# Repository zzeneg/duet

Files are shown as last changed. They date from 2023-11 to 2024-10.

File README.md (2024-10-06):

# duet

Wireless unibody/unsplit portable keyboard.

(https://www.youtube.com/watch?v=R7SToNp1SO8)

> [!NOTE]
> One duet is [available for purchase](https://www.reddit.com/r/mechmarket/comments/1fwzixb/eupl_h_duet_stront40_custom_ergo_keyboards_w/) right now

## Features

- wireless (nice!nano MCU)
- unibody that can be disassembled into two parts for traveling
- 40 Choc V1 switches
- 1 rotary encoder and 1 five-way switch
- reversible PCB
- 3D printed case
- nice!view support

## Photos

https://github.com/zzeneg/duet/assets/910255/740595a8-76a9-42da-903d-3cff3896a925

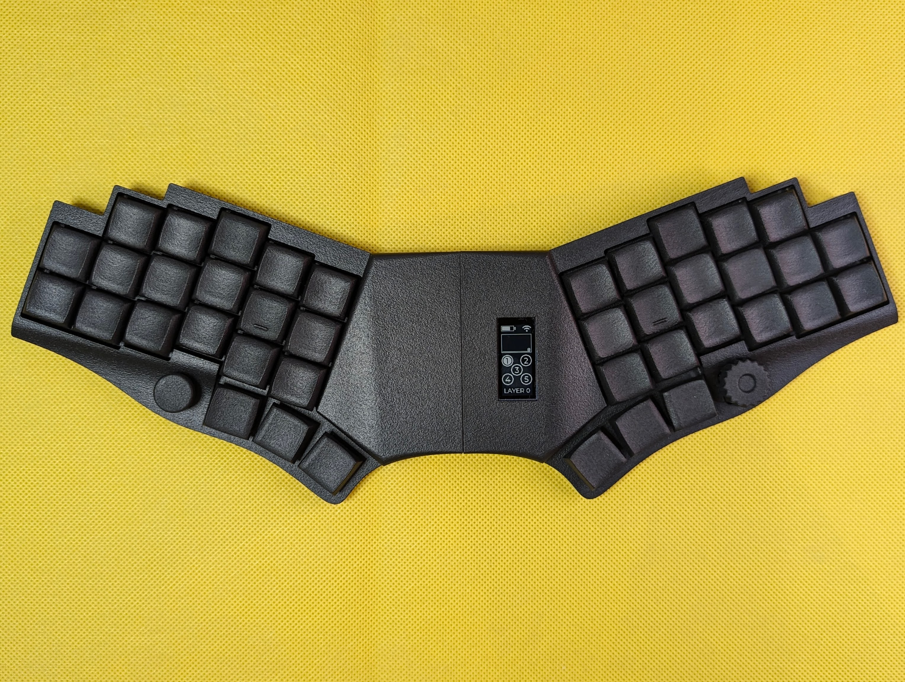
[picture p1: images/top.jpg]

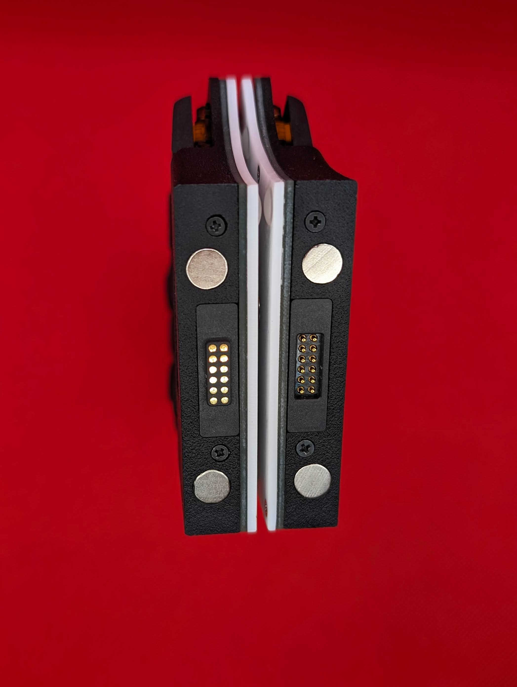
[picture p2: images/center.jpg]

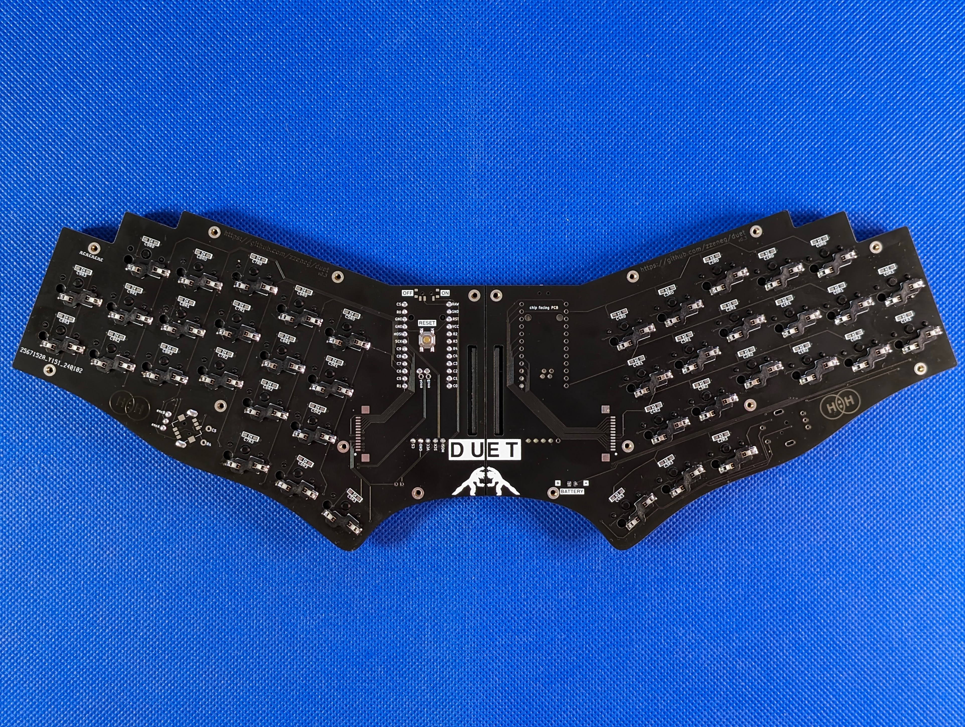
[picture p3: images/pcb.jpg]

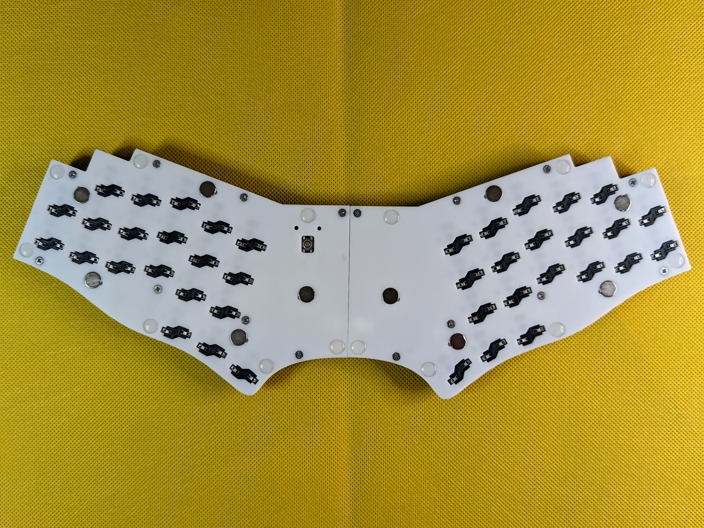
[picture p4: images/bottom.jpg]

[...more](./images)

## Firmware

[zmk-config](https://github.com/zzeneg/zmk-config/tree/duet) - my custom keymap, use it for testing only. Fork and create your own keymap instead.

## Instructions

[Build guide](./guide/readme.md)

All files are available in repo or [GitHub release](https://github.com/zzeneg/duet/releases/latest).

## Support

If you like my work and want to support my future designs, please consider [sponsorship](https://github.com/sponsors/zzeneg).

#### Sponsors



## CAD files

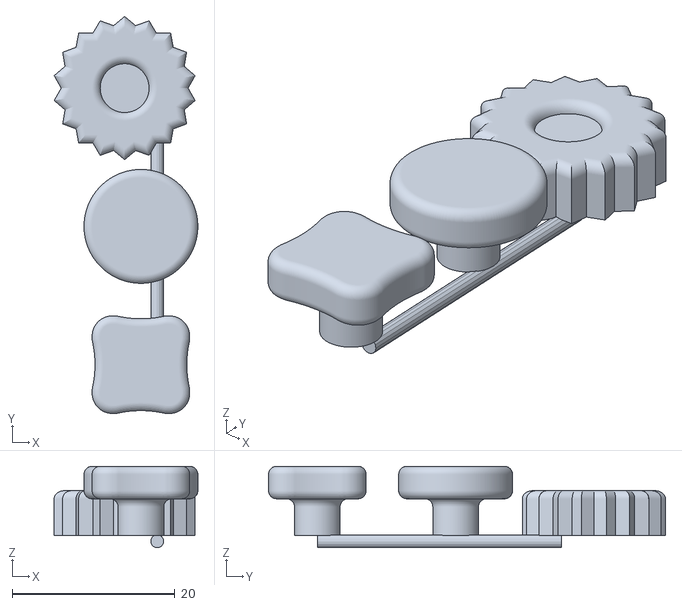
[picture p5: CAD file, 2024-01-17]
case/knobs-all.stl
17.7 x 48.8 x 10.0

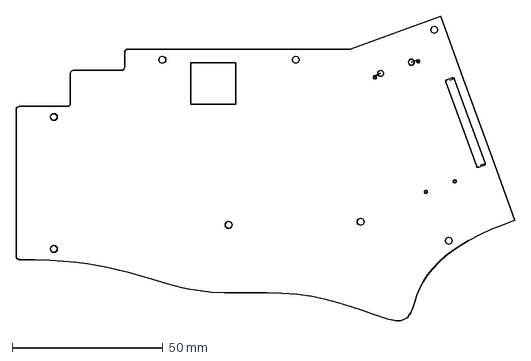
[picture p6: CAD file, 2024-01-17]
pcb/outline.dxf
165.5 x 101.1 mm

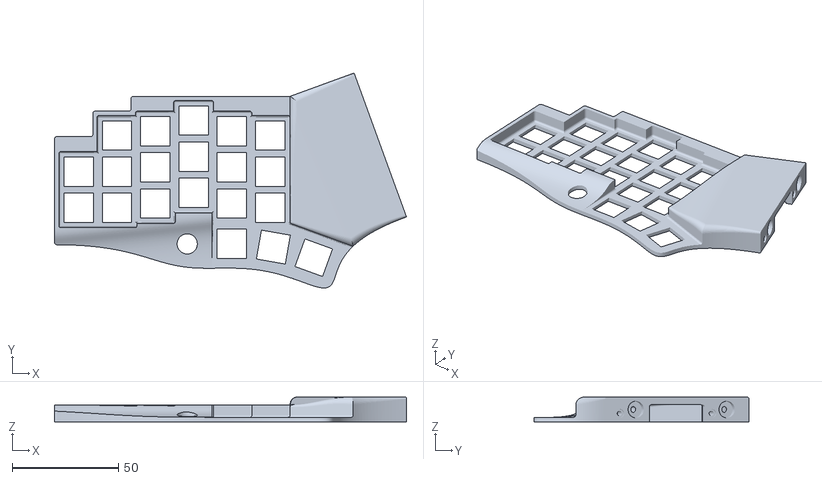
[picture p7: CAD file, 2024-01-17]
case/case_duet v39_top-left-cover.stl
165.5 x 101.1 x 11.7

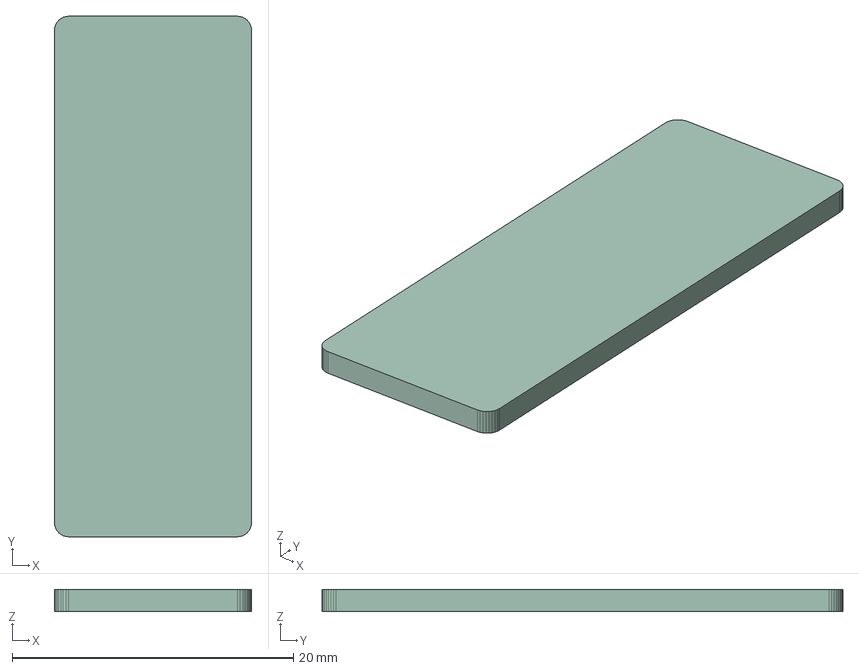
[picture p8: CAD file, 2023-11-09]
pcb/logo.step
14.0 x 37.0 x 1.58 mm

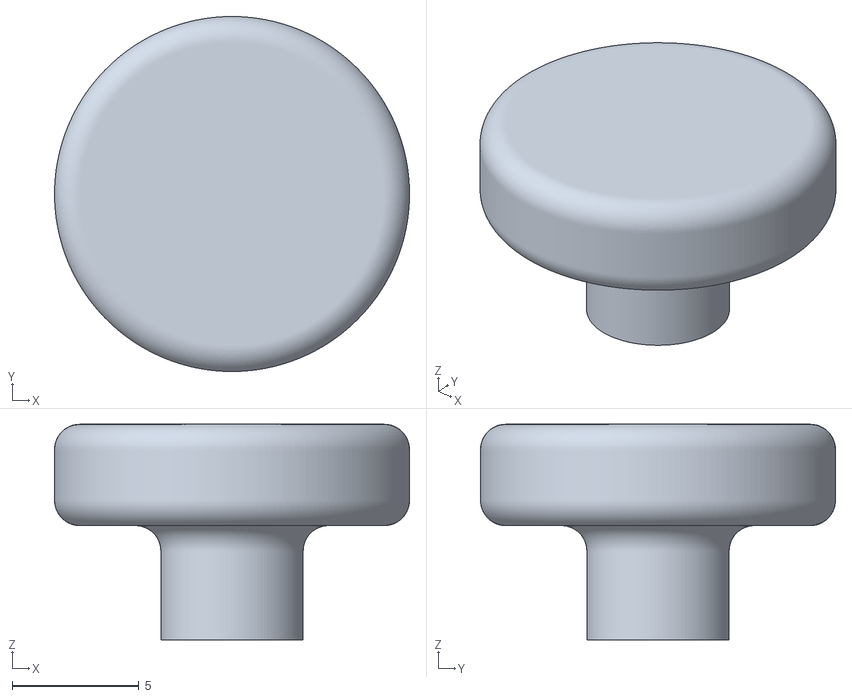
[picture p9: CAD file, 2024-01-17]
case/knob-5way-round.stl
14.0 x 14.0 x 8.50

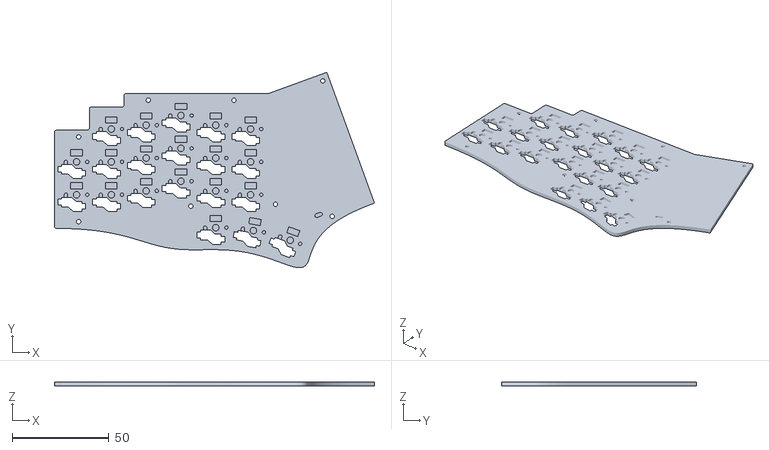
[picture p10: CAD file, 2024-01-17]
case/case_duet v39_bottom-left.stl
165.5 x 101.1 x 2.00

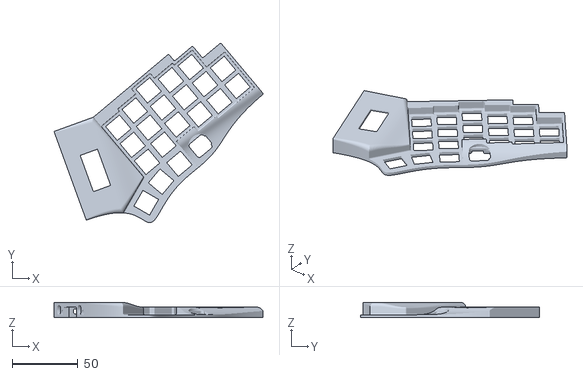
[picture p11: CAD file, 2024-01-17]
case/case_duet v39_top-right-display.stl
159.4 x 136.7 x 11.7

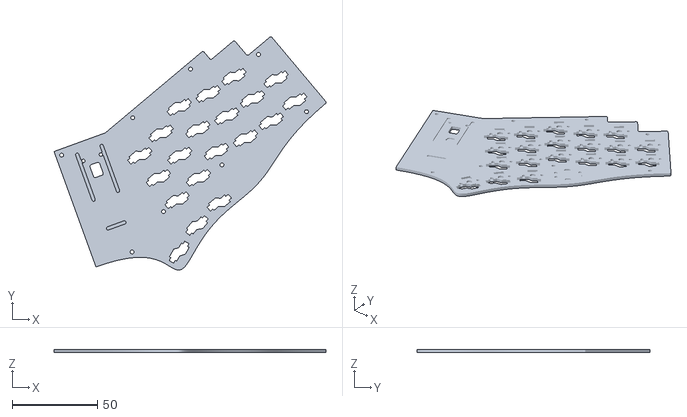
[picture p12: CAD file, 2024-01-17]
case/case_duet v39_bottom-right.stl
159.4 x 136.7 x 2.00

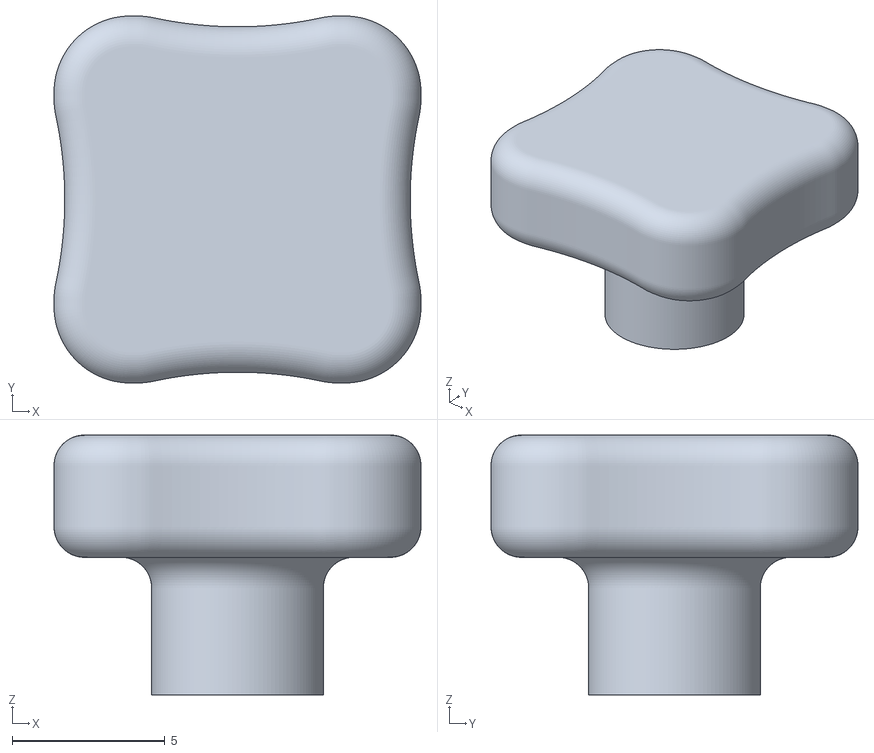
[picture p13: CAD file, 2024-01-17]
case/knob-5way-ergo.stl
12.0 x 12.0 x 8.50

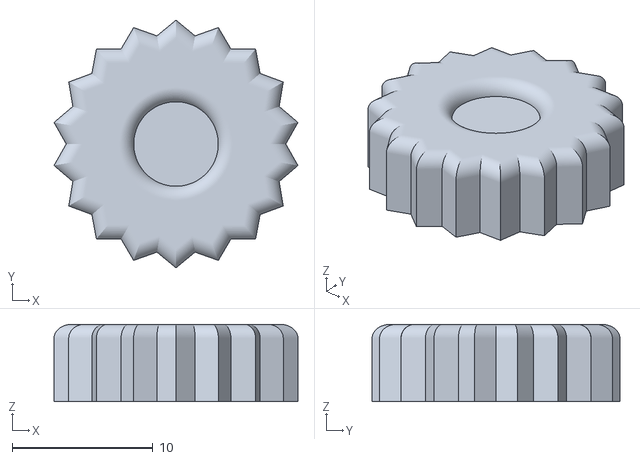
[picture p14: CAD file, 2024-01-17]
case/knob-ec12.stl
17.3 x 17.6 x 5.50

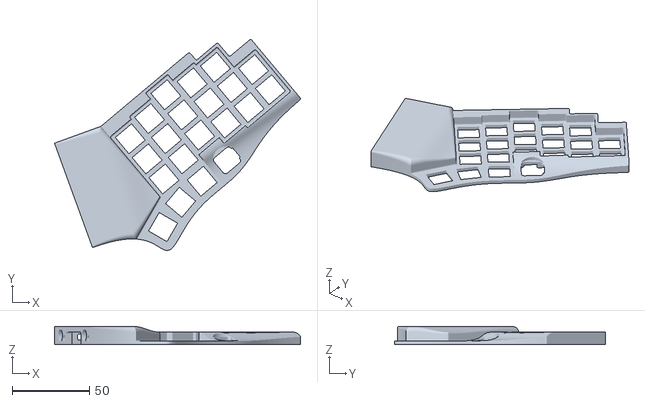
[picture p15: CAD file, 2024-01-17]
case/case_duet v39_top-right.stl
159.4 x 136.7 x 11.7

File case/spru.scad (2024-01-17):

count = 3;
spacing = 17;
r = 0.8;

stl1 ="./knob-5way-ergo.stl";
stl2 ="./knob-5way-round.stl";
stl3 ="./knob-ec12.stl";

union() {
    import(stl1);
    translate([0, spacing, 0]) import(stl2);
    translate([-2, spacing * 2, 0]) import(stl3);

    translate([2, 0, - 0.9 * r])
    rotate ([270, 0, 0])
    cylinder(h = (count) * spacing - 21, r = r, $fn=15)
    ;
};

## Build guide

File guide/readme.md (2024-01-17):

## What to order

All files are availaible in repo or in [Release](https://github.com/zzeneg/duet/releases/latest)

- 2 PCBs - `GERBER-pcb.zip` and `GERBER-connector.zip`. For connector I recommend to select 1.2mm thickness. If using JLCPCB, choose "Specify a location" in "Remove order number". Other settings can be default
- 4 case parts - bottom left, bottom right, top left and top right (with or without display)
- 2 knobs - I recommend `knobs-all.stl` which contains EC12 knob and two knobs for 5 way switch

## Bill of materials

- MCU - nice!nano _(recommended, please support original creator)_ or its chinese clone
- 40 Choc V1 hotswap sockets
- 40 Choc V1 switches
- 40 [SMD SOD-123 1N4148](https://www.aliexpress.com/item/1005002882901030.html) diodes
- Battery up to 602040 size - this is what I'm using, should be enough but you may try to go bigger (check that there's enough space inside using 3D project)
- _[Optional]_ Vertical 2pin 2.54mm JST [connector](https://www.aliexpress.com/item/1005004938361514.html) for battery
- [Magnetic connector 12pin](https://www.aliexpress.com/item/1005004609718442.html)
- 1 EC11/EC12 rotary encoder, [low profile EC12](https://www.aliexpress.com/item/1005003636548797.html) is recommended (no click though)
- 1 Alps SKRH 5-way switch, [SKRHADE010](https://www.aliexpress.com/item/1005005687595092.html) (more tactile) or [SKRHABE010](https://www.aliexpress.com/item/1005004045054939.html)
- 6mm, 8mm and 10mm [M2 screws with flat head](https://www.aliexpress.com/item/4001248931159.html) (choose black or silver based on case color/preference)
- [M2 nuts](https://www.aliexpress.com/item/1005001412230125.html)
- Vertical 12pin 1mm [FFC/FPC connector](https://www.aliexpress.com/item/1005003970200102.html)
- Horizontal 12pin 1mm [FFC/FPC connector](https://www.aliexpress.com/item/10000348360254.html)
- 12pin 1mm pitch 6cm [FFC cable](https://www.aliexpress.com/item/10000013182312.html) - grab both reverse and same side variants, in case you solder the connector upside down
- SMD 4x4x1.5mm [push button](https://www.aliexpress.com/item/32802382507.html)
- MSK-12C02 on/off switch
- [7x1.5mm legs](https://www.aliexpress.com/item/1005002995402961.html)
- [8x1.5mm magnets](https://www.aliexpress.com/item/1005005884332595.html)
- 2.54mm female pin [headers](https://www.aliexpress.com/item/4001122376295.html)
- 5pin [headers](https://www.aliexpress.com/item/1005005742644313.html) - source of pins for socketing, and also a connector for nice!view
- M2 4mm [heatset inserts](https://www.aliexpress.com/item/1005004624377733.html) - diameter 3.2mm for resin case or 3.5mm for thermoplastic

If using nice!view:

- [5pin female RGBW cable](https://www.aliexpress.com/item/1005002644712420.html)

## Tools

- Soldering iron. Any iron will work, but I highly recommend something small like TS100 or Pinecil with TS-K tip, it's good for SMD soldering
- Solder wire, preferably with lead if you can get one. For EU I recommend this [shop](https://botland.store) and Cynel brand, 0.56mm and 0.9mm
- [Flux](https://www.aliexpress.com/item/1005004675178847.html)
- Flush cutters - be extra careful when cutting pins, always use eye protection
- Hot glue (for nice!view only), instant glue (for resin case only)
- Tweezers (I prefer [reverse](https://www.aliexpress.com/item/1005004188266714.html) instead of regular), pliers, soldering mat, isopropyl alcohol (IPA) and [cotton pads](https://www.aliexpress.com/item/1005003798227116.html) for cleaning

## Preparations

- download sample firmware, flash it to MCU and pair with your PC. It's easier to do it now and also check that MCU actually works
- read through the whole build guide. Split your components into three groups - left side, right side and connector

## Left side

1. Left side components:

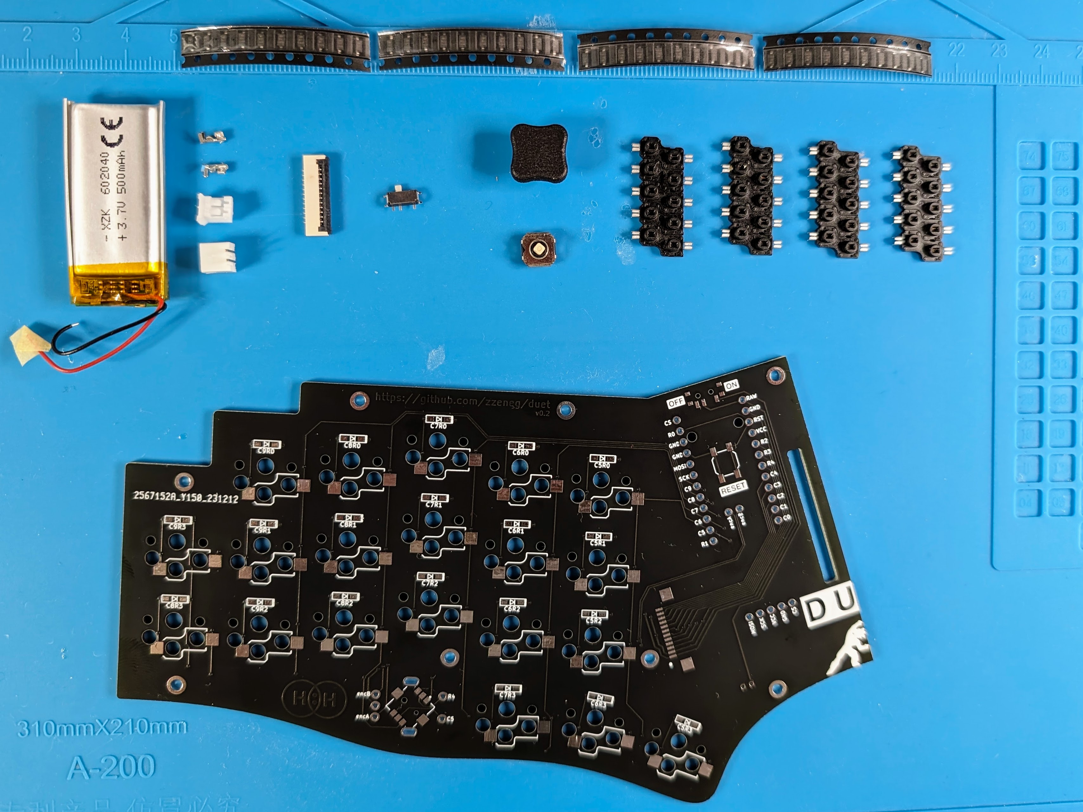
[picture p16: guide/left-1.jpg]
   

2. Start from FFC connector, so you'll not be able to mix left and right sides anymore. As with any SMD part, start with putting some solder on only **one** big pad.

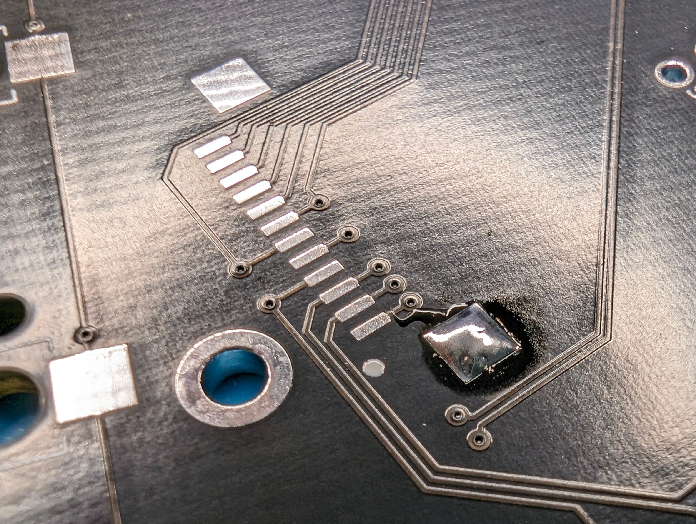
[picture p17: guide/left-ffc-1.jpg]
   

   Put the part into place, heat the solder blob and align the part to match other pads.

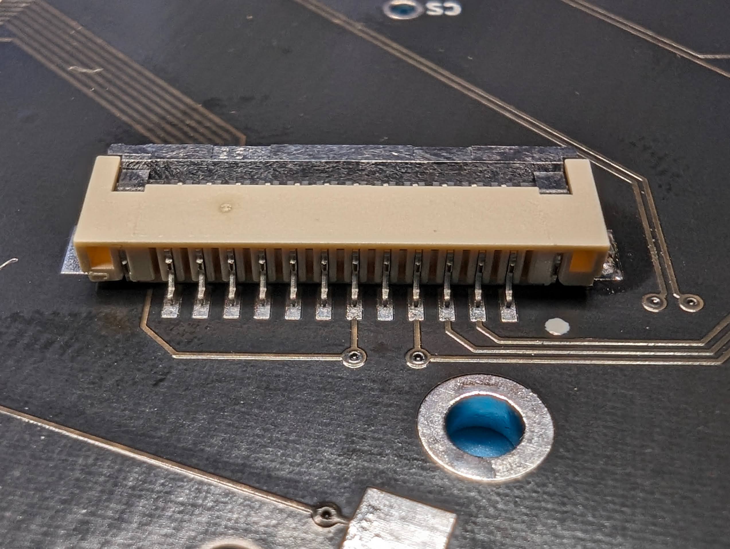
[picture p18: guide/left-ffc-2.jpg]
   

   Solder the second big pad, then proceed to pins. Don't drag the iron across pins, just solder them with the tip one by one, slowly and carefully. Use flux if you have it, clean with IPA afterwards.

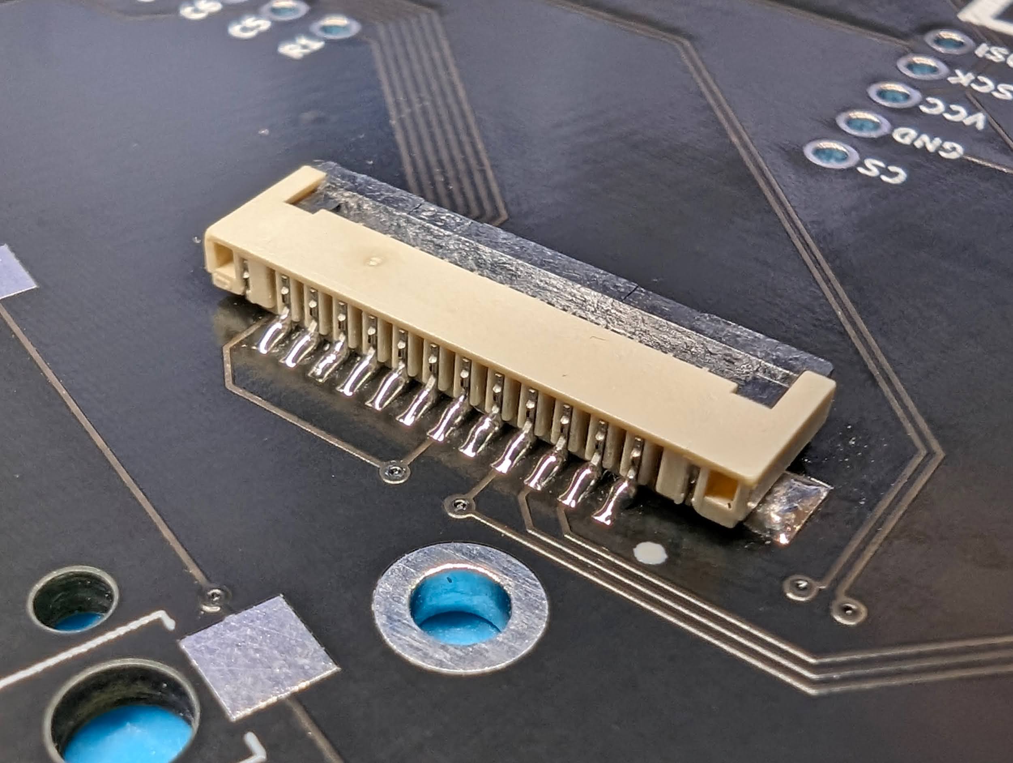
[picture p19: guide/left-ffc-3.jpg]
   
   
   If any pins are bridged, add flux and remove extra solder by moving the iron along the pin from component to you. Again, slowly and patiently, it can take multiple tries but you can do it.

3. Solder on/off switch. Same approach - start with one pad, put switch into place and finish other pins.

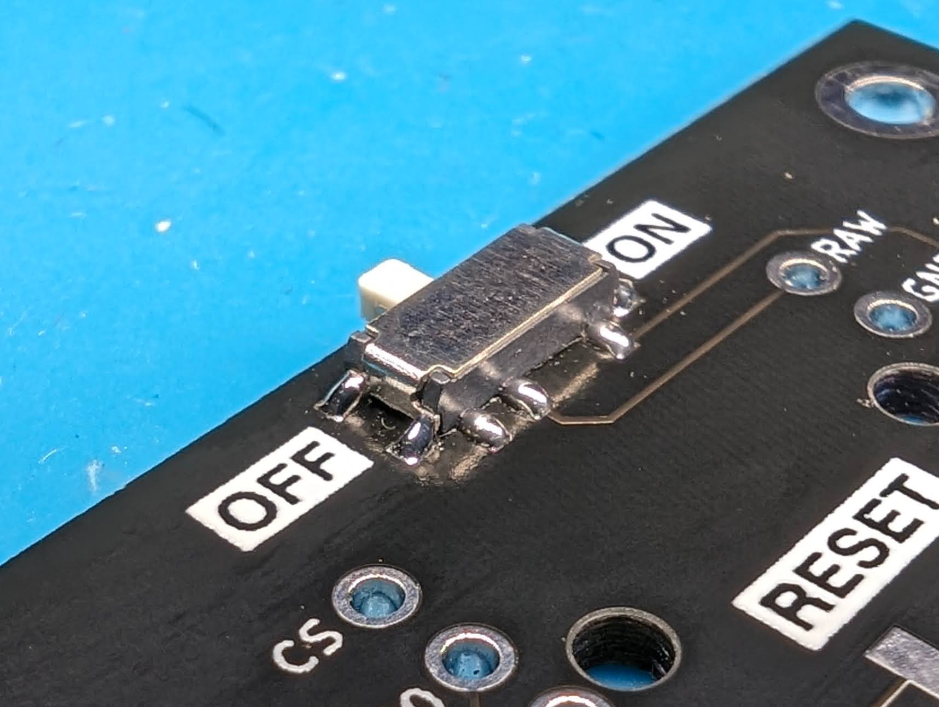
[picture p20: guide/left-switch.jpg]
   

4. Time for diodes. The PCB and case supports diodes both on any side. I prefer putting them on top inside switch's LED hole - it's pretty big and allows more relaxed placement. As to my knowledge, all Choc switches support LEDs, but double check your switches to be sure.

   Diodes are **not** symmetrical, make sure you're placing them correctly. Every diode has a vertical line on it marking the side with cathode, experiment with lighting and angle if you don't see it. That line should match with a vertical line inside the PCB's footprint and a thick border line (so you can verify it after soldering).

   Start with one pad, use tweezers to put the diode into place. Make sure to press on it with fingernail to avoid it floating in the air. Double check diode's orientation and solder second pad. If you're comfortable with SMD soldering already I recommend to do one pad for all diodes first, then place them and solder second pad for all of them at once.

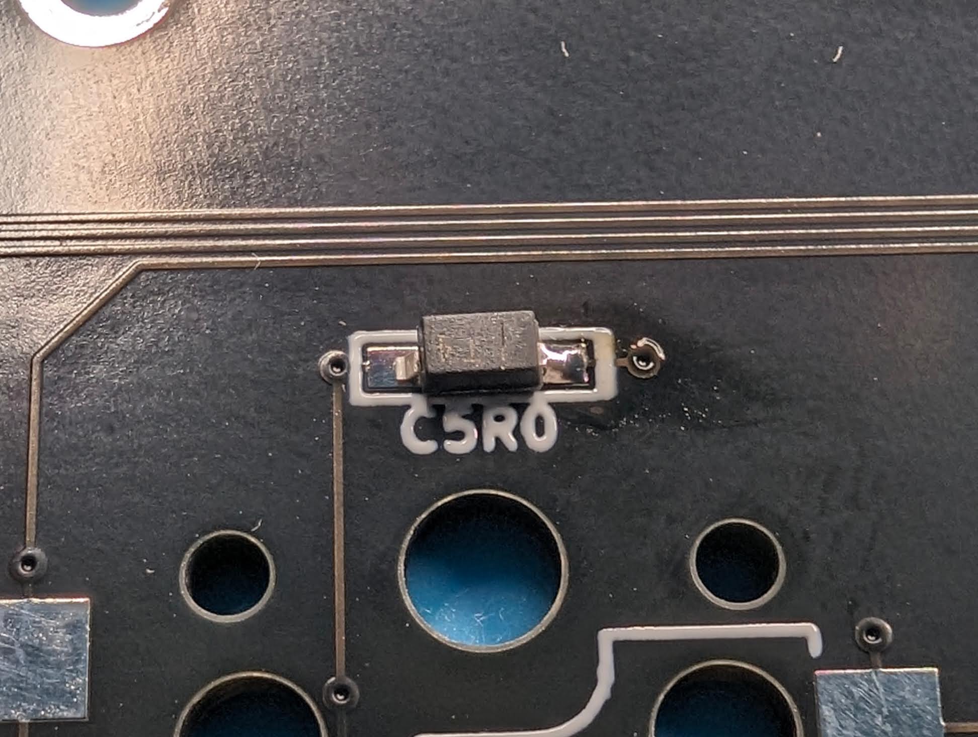
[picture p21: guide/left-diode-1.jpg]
   

5. **Flip** the PCB, let's do hotswap sockets now. Much easier to work with, thicker solder wire is recommended, you'll need a lot. Sockets are not symmetrical, look at silkscreen on how to place it. Approach is still the same - first pad, then socket, then second pad. Make sure that socket is fully inserted into the PCB.

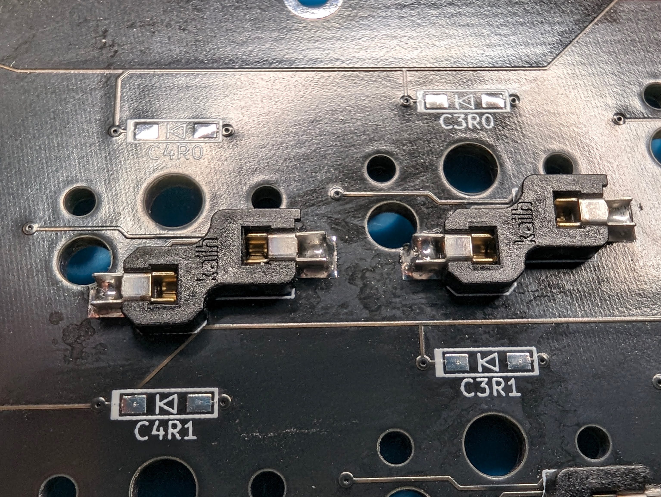
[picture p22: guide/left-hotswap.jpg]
   

6. _[Optional]_ Solder JST battery connector. When attaching a battery, double check polarity, positive side (red wire) must match with + symbol on silkscreen - depending on your battery you may have to swap wires inside the connector. You can fix the battery in place with tape (use removable tape and/or try it inside the case first).

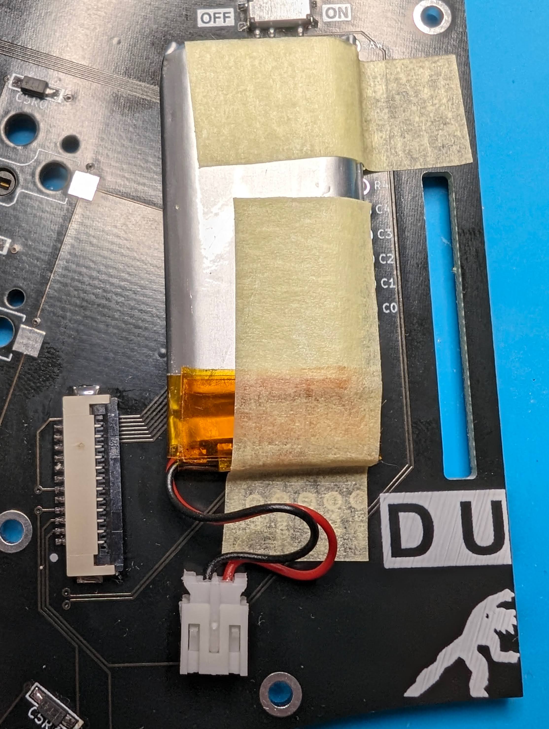
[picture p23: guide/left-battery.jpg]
   

7. Flip PCB again, last part - 5 way switch. It's not symmetrical, there is only one way you can insert it so do not force it. Start with big pads, finish with small ones.

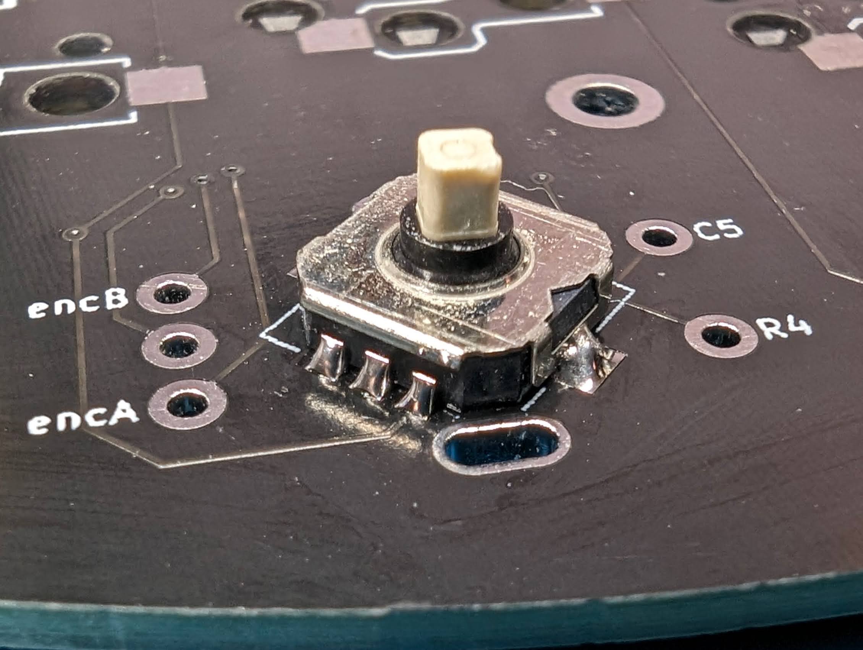
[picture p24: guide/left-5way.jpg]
   

   Left side is finished, congratulations!

## Right side

1. Right side components:

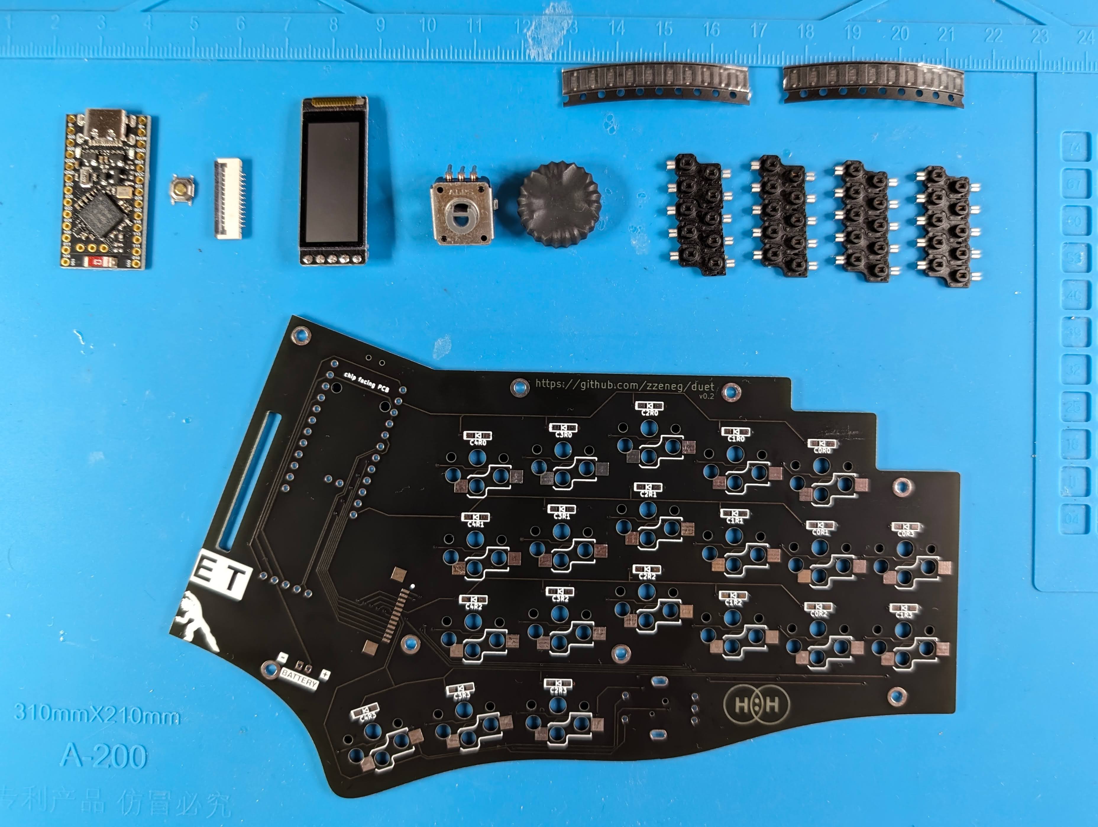
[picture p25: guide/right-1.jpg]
   

2. Same as the left side - start with FFC, then diodes and sockets (on the bottom side).

3. Prepare MCU headers - you'll need two strips of 12 pins and one of 2. Don't try to break the header between the pins, instead count the required number of pins, and break in middle of a next pin. Discard that pin and cut the plastic with flush cutters - it'll look much better. Assemble headers like this (using extra headers for stabilization):

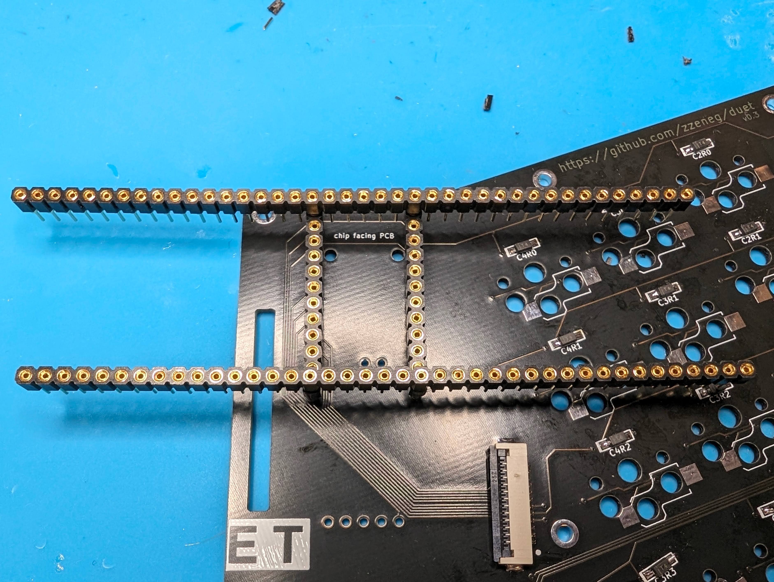
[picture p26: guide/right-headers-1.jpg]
   

   Flip carefully and solder all pins starting from corners. I prefer to cut first and then solder but you can cut afterwards as well, just remember to do it as bottom case has only 1.2mm space there.

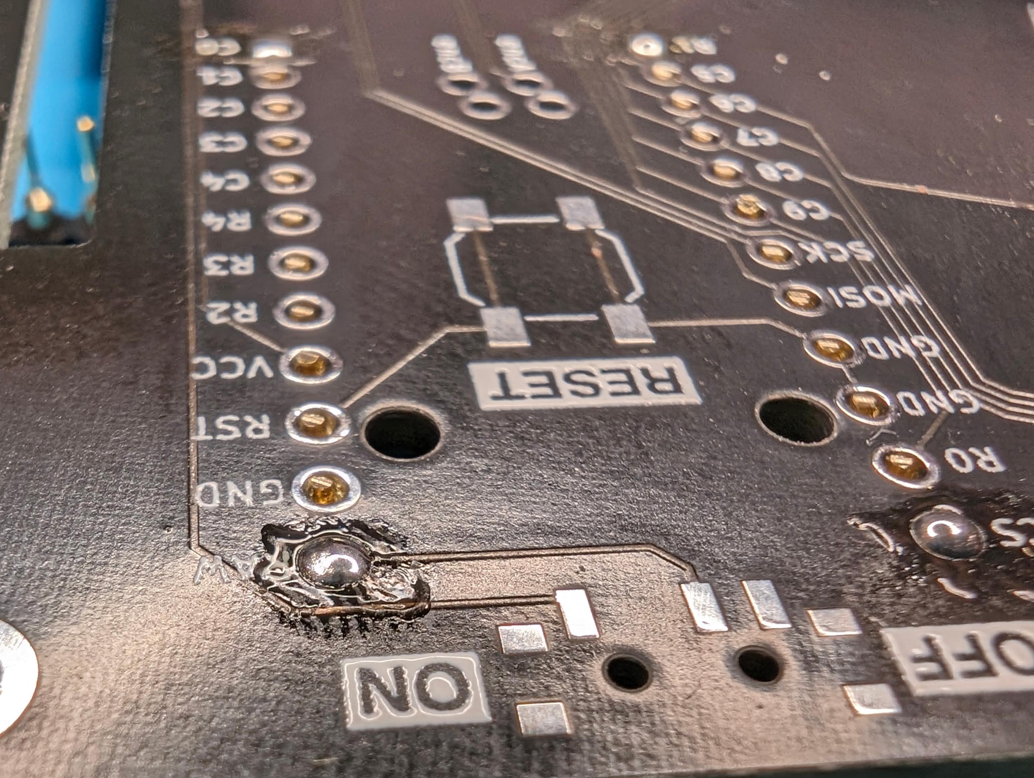
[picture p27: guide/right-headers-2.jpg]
   

   If you're using original nice!nano: insert 2-pin header into **top** holes (like on photos) and fix it in place with an extra pin header. If you're using clone: insert 2-pin header into **bottom** holes and fix it in place with tape (holes are not aligned so you can't use headers). Flip and solder.

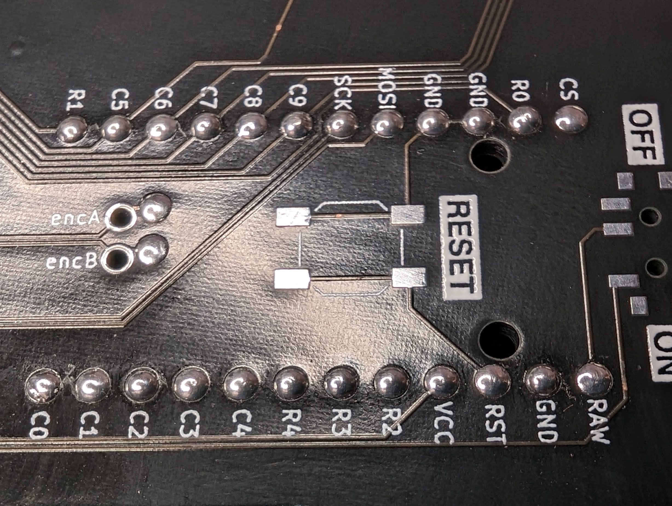
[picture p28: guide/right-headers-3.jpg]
    

5. Solder reset button. SMD parts should be a piece of cake for you already, so no photos :)

6. Time to actually socket the MCU.

   For **nice!nano** users - you have to cut plastic around the pin in the middle, n!n has some component in that place:

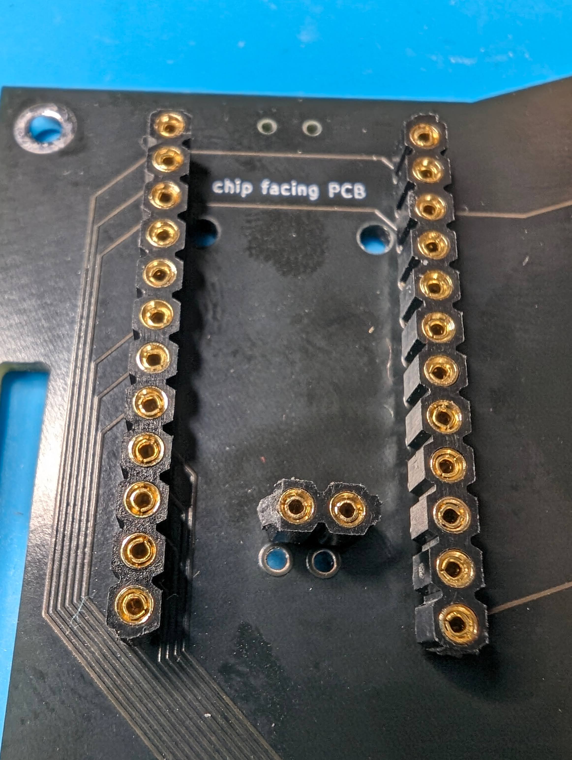
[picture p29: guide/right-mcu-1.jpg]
   

   Pull out 24 pins from RGB headers and put a piece of masking tape over all headers leaving some space in between for MCU components.

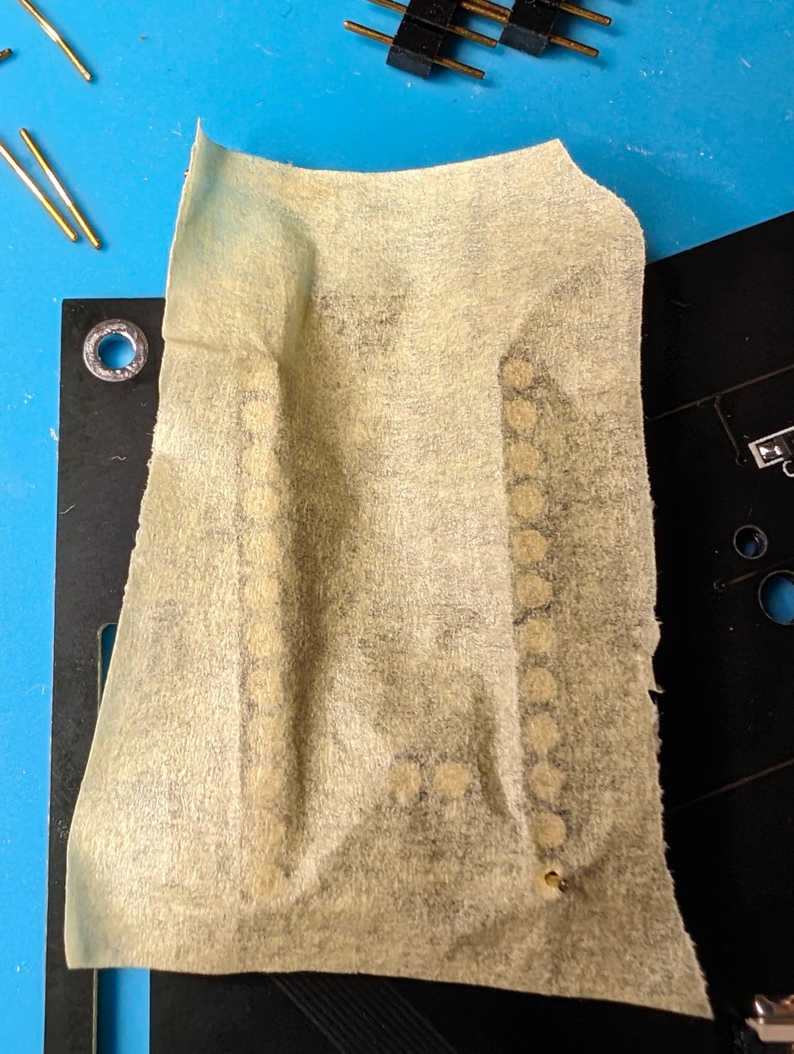
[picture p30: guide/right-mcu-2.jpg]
   

   Align MCU holes with headers (remember to ignore top holes on MCU, they are not used/soldered) and insert pins one by one. Cut them if you prefer but it's not required. Solder everything starting from corners. For **nice!nano** be extra careful not to bridge middle pins with SWC pad.

   Carefully extract MCU, remove tape and insert it back. Done!

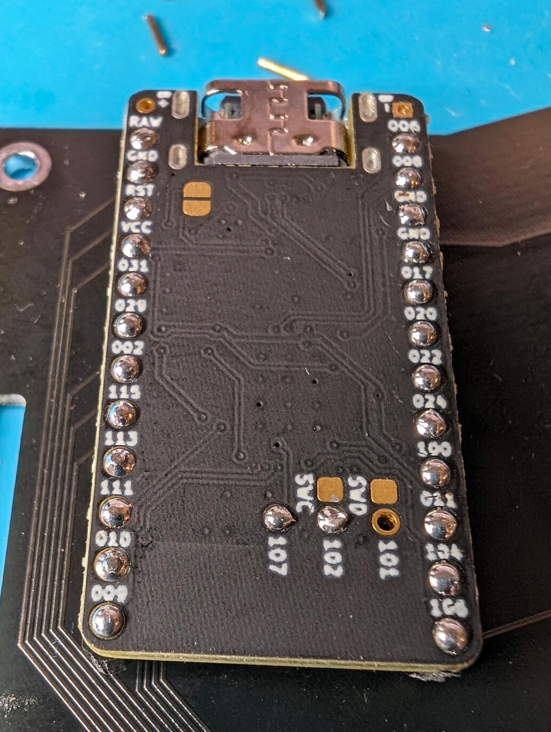
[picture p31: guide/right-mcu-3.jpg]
   

7. Solder rotary encoder, remember to cut pins under 1.2mm.

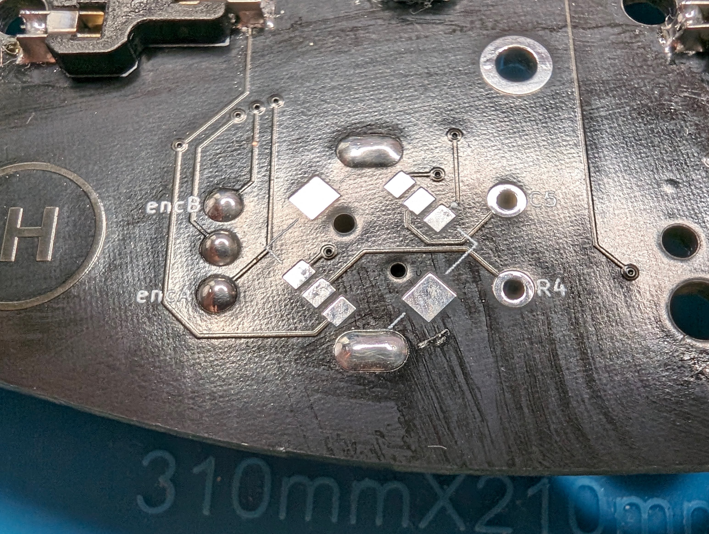
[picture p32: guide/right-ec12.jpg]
   

8. _[Optional]_ **nice!view**. You could solder it with wires directly but I like to socket it similar to MCU to make disassembly much easier. Cut the RGB strip to 6.5-7cm, clean the ends and solder them to **keyboard** PCB.

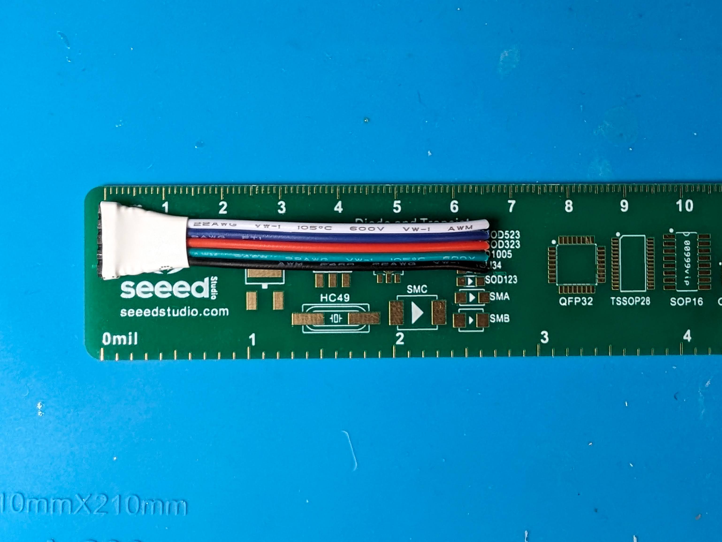
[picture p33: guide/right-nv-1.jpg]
   

   Take an RGB header, bend pins on one side, insert it into nice!view and solder. Do not bend the header inside nice!view to avoid damaging the display.

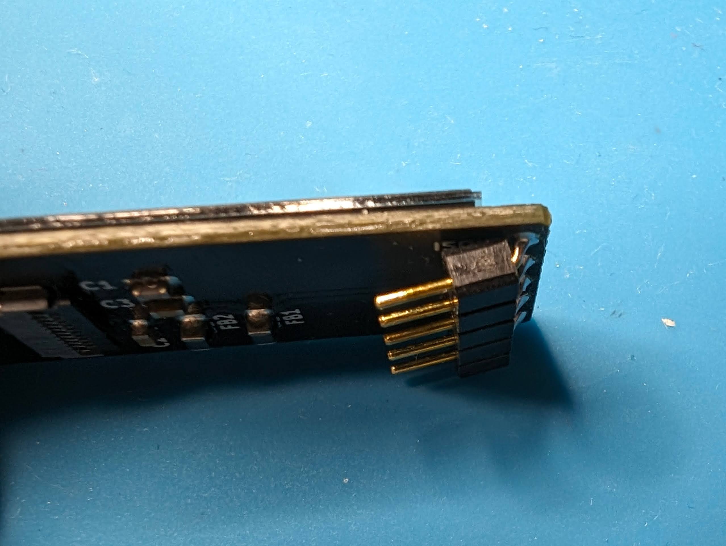
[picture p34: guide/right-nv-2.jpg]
   

   Glue nice!view to the case with hot glue or tape.

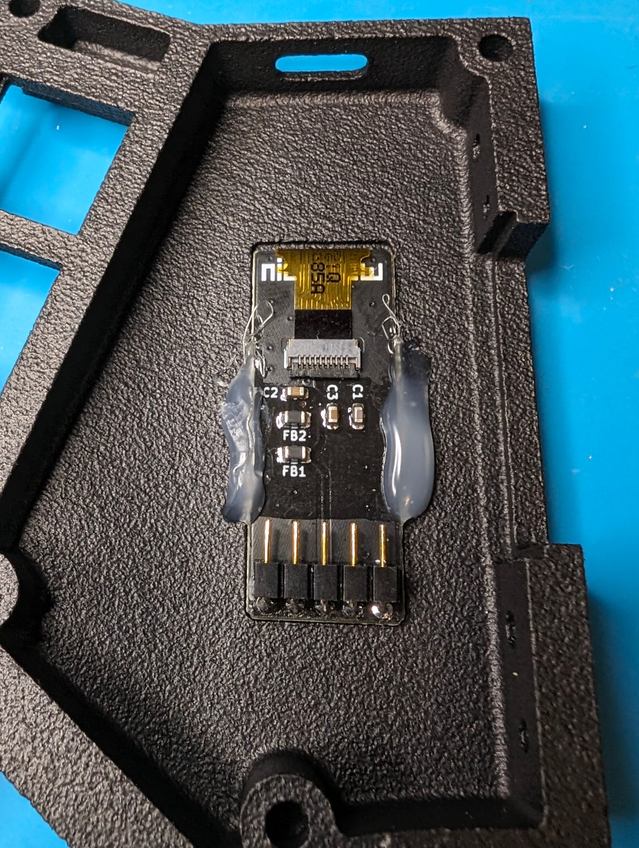
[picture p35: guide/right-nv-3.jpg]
   

   Bend the wire into an S letter (see photo), attach it to nice!view and try to close the case, the wire must bend before reaching MCU:

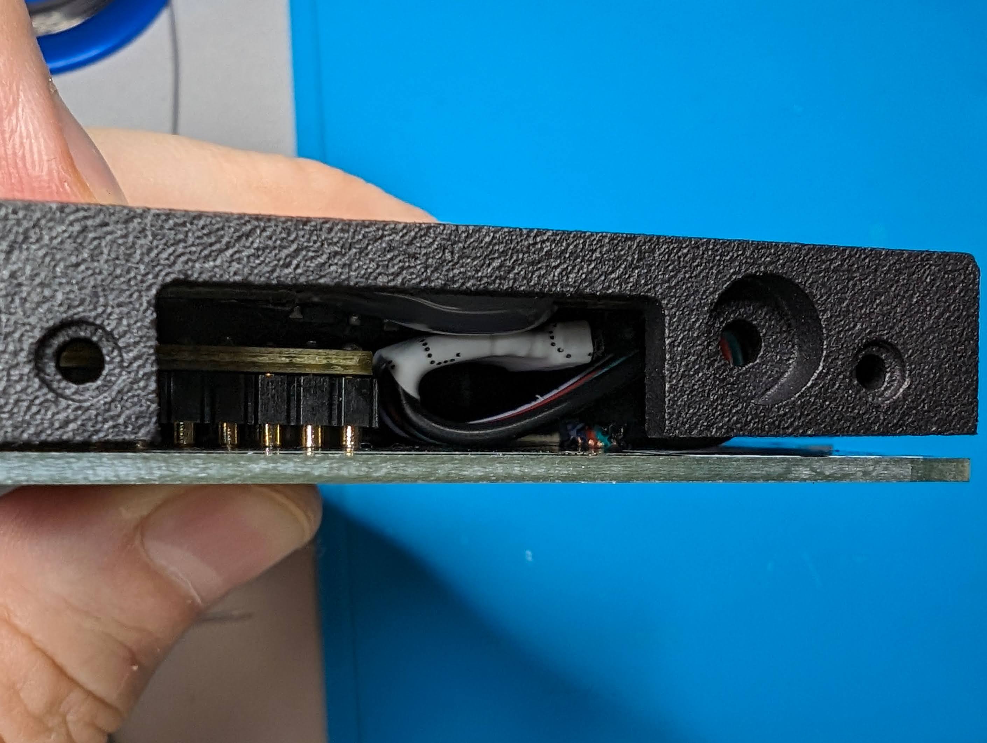
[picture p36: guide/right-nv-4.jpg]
   

   Right side is completed.

## Connectors

Now this part is a bit confusing, look carefully on the photos and triple check your magnets for correct orientation.

1. Prepare two connector PCBs, and put them down on **different** sides (for example jlcpcb's order number should be visible only on one of them). Rotate so that version number (`0.3`, `1.0`, etc) is on top. Solder vertical FFC connectors, black part must be on **top** (next to version number). If you still soldered it upside down, don't worry and use another FFC cable (with contacts on different sides).

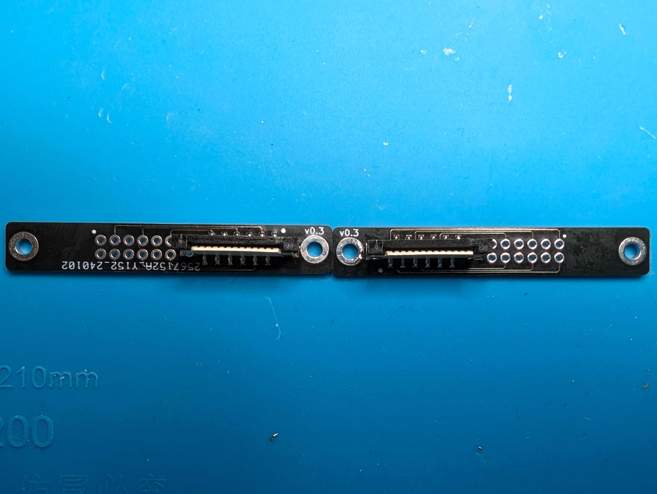
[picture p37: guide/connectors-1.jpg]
   

2. Take magnetic connectors and put some tape on magnets to isolate them, otherwise they'll short PCB pads.

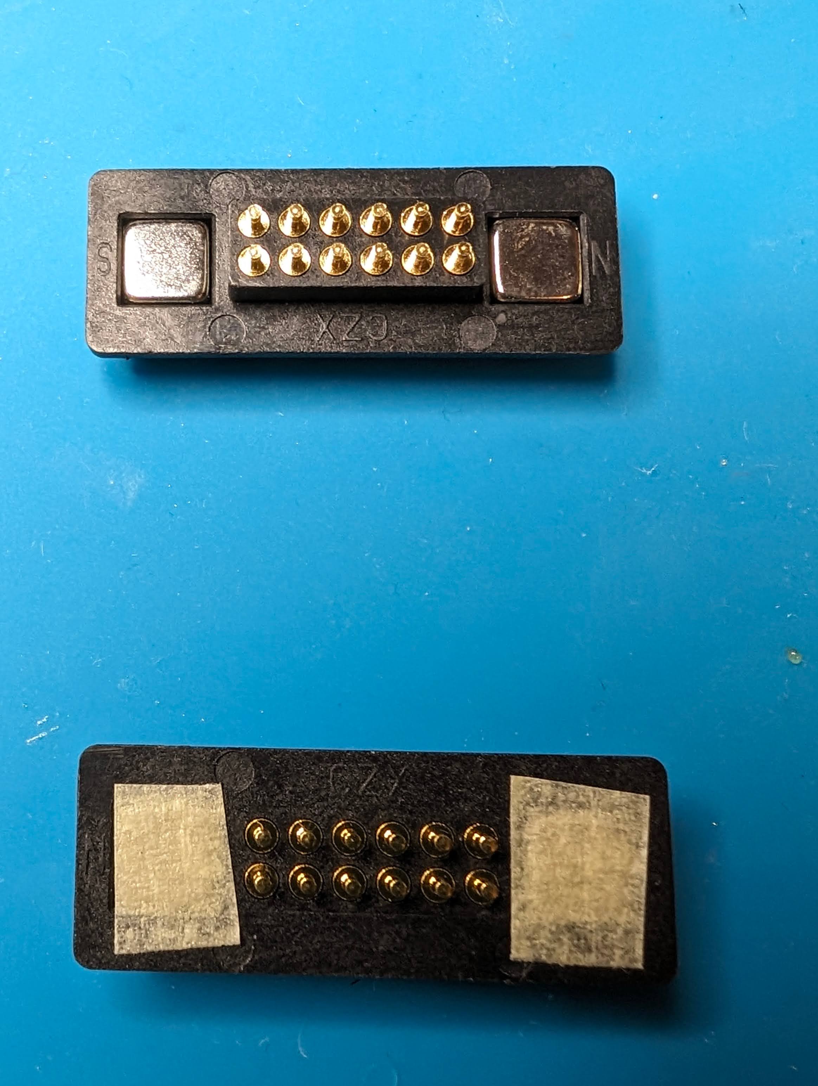
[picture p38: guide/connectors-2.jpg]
   

3. Put PCBs onto connectors and double check that magnets are oriented correctly

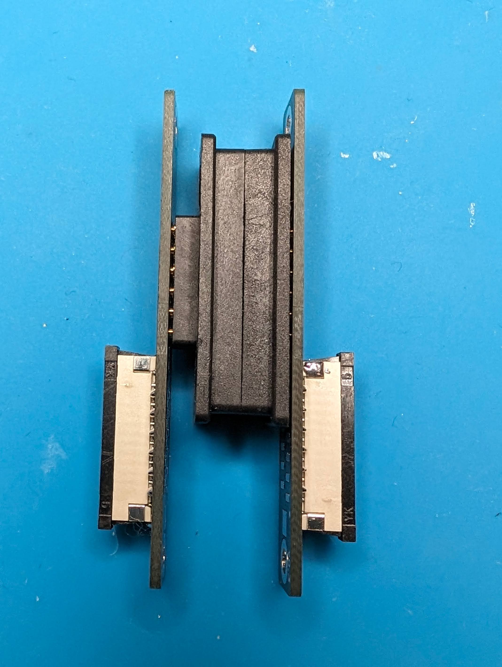
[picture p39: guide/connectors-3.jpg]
   

4. Take them apart and solder without flipping anything. It's a bit tricky because of magnets but doable with two hands. The easiest approach is to add a lot of flux and drag solder across all contacts.

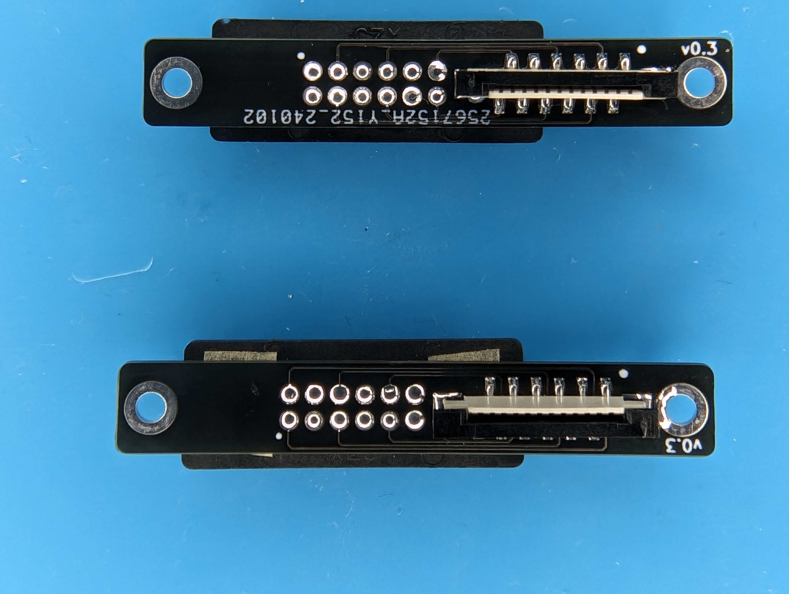
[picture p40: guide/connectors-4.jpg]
   

5. Attach connectors to the case. Black part of the FFC connector should not be visible, the wider connector should go to left (battery) side. Use 8mm and 10mm screws (on the photo I used 12mm screws as I didn't have 10mm, it'll look better for you).

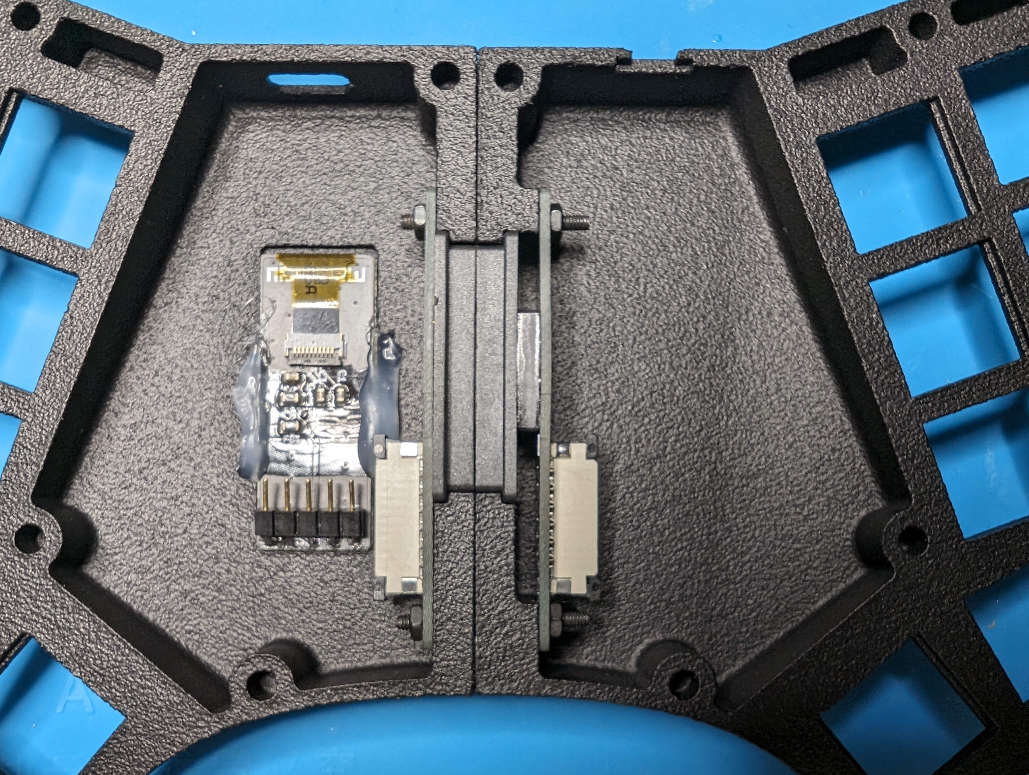
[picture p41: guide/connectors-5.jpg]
   

6. Insert magnets into the case. Holes are 3mm deep so they take two magnets. They overlap with connector's magnets a bit so try both sides - one will go easier than the other. 

## Case assembly

1. Put screw inserts into the case. For resin case take 3.2mm-wide inserts and use instant glue (cyanoacrylate), for thermoplastics (MJF, PLA, etc) use 3.5mm and look at [this guide](https://docs.bastardkb.com/bg_charybdis/04screw_inserts.html) for detailed instructions on heat inserts.

2. Assemble top case and PCB together, connecting main PCB to connectors with FFC cables (same side contacts). I think it's easier to insert it into connector first, and then into main PCB.

3. Connect both parts together, perform some basic testing - display, 5-way switch, encoder - everything should work already. I recommend to also test every key by shorting hotswap socket with some metal tool (switch puller, pliers, etc).

4. If everything is ok - congratulations! Close the case with bottom part and 6mm screws, don't overtight them.

5. Attach legs and magnets to the bottom, insert switches and keycaps.

## Troubleshooting

#### Nothing works
- try with USB cable
- check that firmware is uploaded
- reset BT on the keyboard, pair/unpair - see [ZMK docs](https://zmk.dev/docs/behaviors/bluetooth)
- check connection status (if using display)

#### Whole row/column does not work

- check continuity from controller pin to problematic row/column (use schematic or silkscreen to trace exact pin). Weak points - MCU sockets, FFC connectors, magnet connectors

#### Single key does not work

- check that switch is inserted correctly, you should see both pins inside the hotswap socket
- short hotswap socket manually, if it works - move the hotswap springs closer to each other
- check that hotswap socket is soldered correctly
- use multimeter to check diode orientation, you can do it from bottom side as well
- check that diode is soldered

#### Display does not work

- check soldering on display connector
- try my original firmware

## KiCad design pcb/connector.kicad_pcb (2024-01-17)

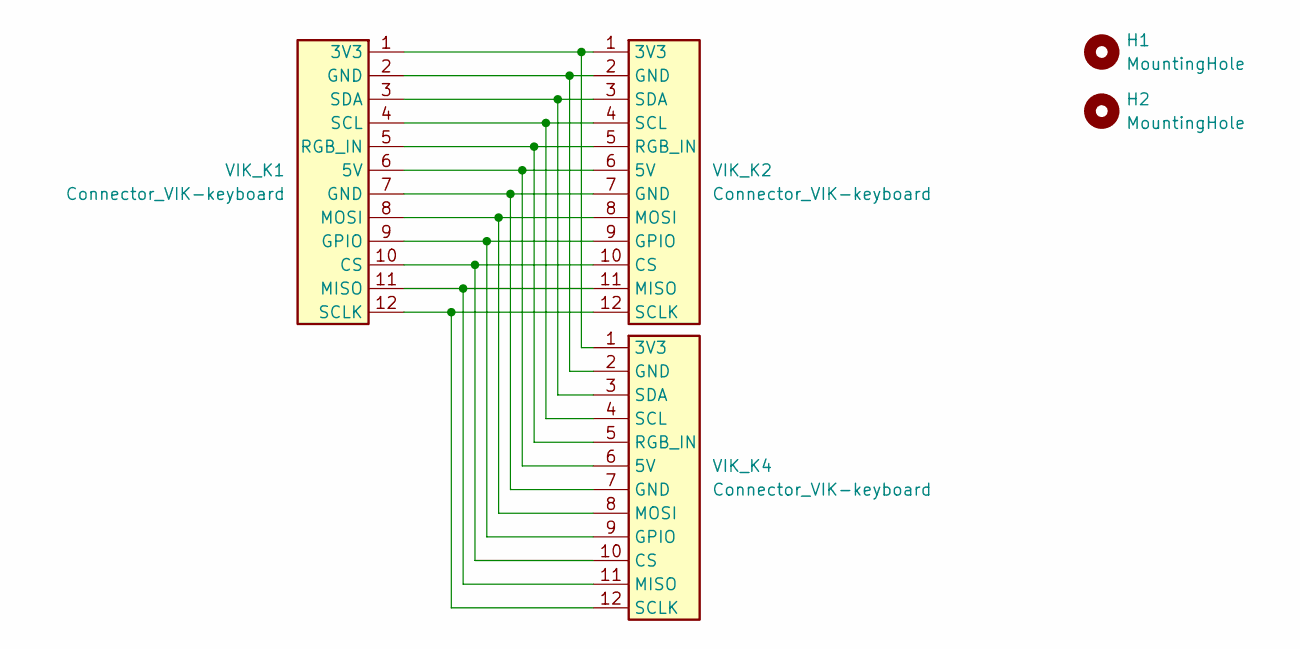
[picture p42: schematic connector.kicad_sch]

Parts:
H1, H2: MountingHole; Hole_M2-TH
VIK_K1: Connector_VIK-keyboard; Connector_VIK-magnetic-keyboard
VIK_K2, VIK_K4: Connector_VIK-keyboard; Connector_FFC-12pin-1mm-vertical

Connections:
unnamed: VIK_K1.1 (3V3), VIK_K2.1 (3V3), VIK_K4.1 (3V3)
unnamed: VIK_K1.6 (5V), VIK_K2.6 (5V), VIK_K4.6 (5V)
unnamed: VIK_K1.10 (CS), VIK_K2.10 (CS), VIK_K4.10 (CS)
unnamed: VIK_K1.2 (GND), VIK_K2.2 (GND), VIK_K4.2 (GND)
unnamed: VIK_K1.7 (GND), VIK_K2.7 (GND), VIK_K4.7 (GND)
unnamed: VIK_K1.9 (GPIO), VIK_K2.9 (GPIO), VIK_K4.9 (GPIO)
unnamed: VIK_K1.11 (MISO), VIK_K2.11 (MISO), VIK_K4.11 (MISO)
unnamed: VIK_K1.8 (MOSI), VIK_K2.8 (MOSI), VIK_K4.8 (MOSI)
unnamed: VIK_K1.5 (RGB_IN), VIK_K2.5 (RGB_IN), VIK_K4.5 (RGB_IN)
unnamed: VIK_K1.4 (SCL), VIK_K2.4 (SCL), VIK_K4.4 (SCL)
unnamed: VIK_K1.12 (SCLK), VIK_K2.12 (SCLK), VIK_K4.12 (SCLK)
unnamed: VIK_K1.3 (SDA), VIK_K2.3 (SDA), VIK_K4.3 (SDA)

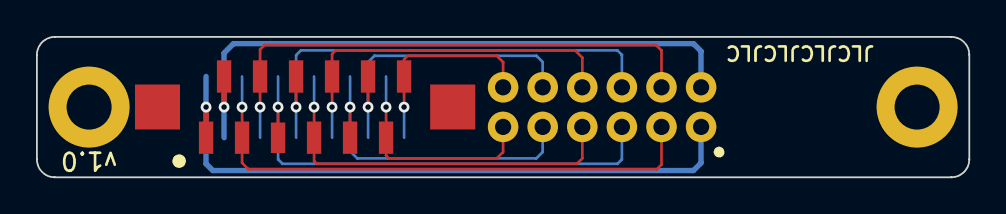
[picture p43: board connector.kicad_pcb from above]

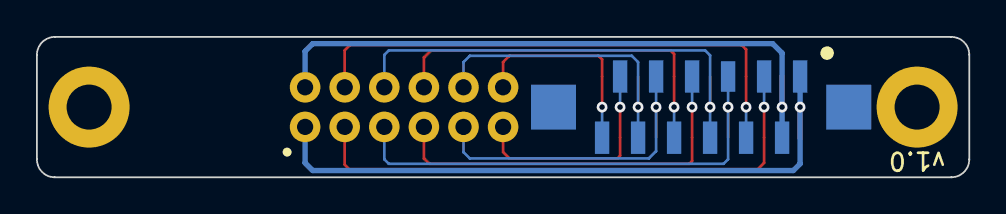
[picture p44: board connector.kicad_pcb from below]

Board: 2 copper layers, 51.8 x 7.8 mm, 5 parts (2 on the bottom side), 12 nets.

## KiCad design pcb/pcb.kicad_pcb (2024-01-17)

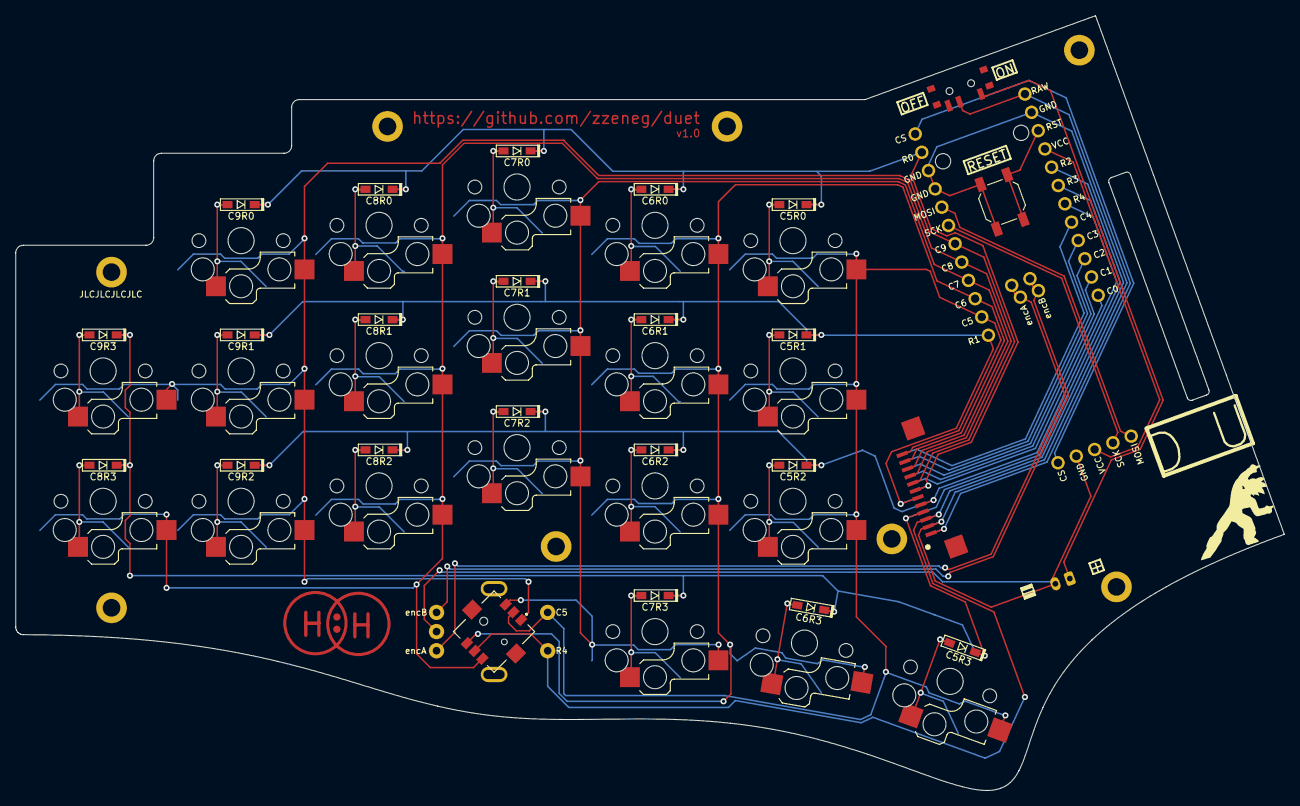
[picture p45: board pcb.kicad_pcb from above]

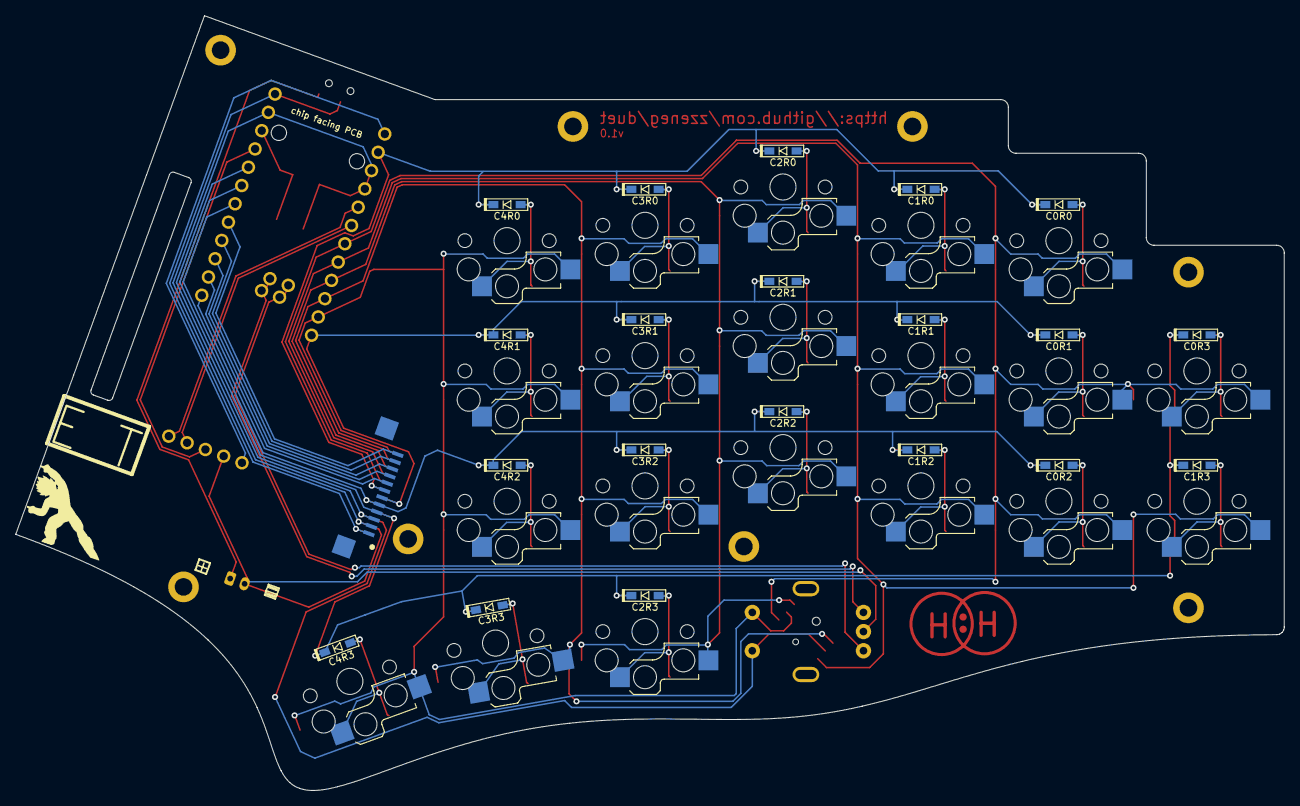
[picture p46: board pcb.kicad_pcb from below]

Board: 2 copper layers, 165.5 x 101.1 mm, 57 parts (23 on the bottom side), 45 nets.

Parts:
D1, D2, D3, D4, D5, D6, D7, D8, D9, D10, D11, D12, D13, D14, D15, D16, D17, D18, D19, D20: D; Diode_1N4148-SOD123-reversible-flip3d
H1, H2, H3, H4, H5, H6, H7, H8: MountingHole; Hole_M2-TH
J1: N!N; MCU_nice-nano
J2: Conn_01x02_Socket; Connector_JST-1x02-2.00mm
J4: Display_nice-view
J8, J9: Conn_01x12_Socket; Connector_FFC-12pin-1mm-horizontal
S1: Button_5way-SKRHABE010
SW1, SW2, SW3, SW4, SW5, SW6, SW7, SW8, SW9, SW10, SW11, SW12, SW13, SW14, SW15, SW16, SW17, SW18, SW19, SW20: Switch; Switch_ChocV1-hotswap-reversible
SW21: SW_Push; Button_SW_SPST_SKQG_WithoutStem
SW22: SW_SPDT; Switch_SPDT-PCM12
SW23: RotaryEncoder_Switch; RotaryEncoder_EC11

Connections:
+3.3V: J1.21 (3V3), J4.3 (VCC)
BAT: J1.24 (BAT), J8.1, J9.12, SW22.2 (B)
BATIN: J2.1, SW22.1 (A)
CS: J1.1 (006), J4.5 (CS)
GND: J1.3 (GND), J1.4 (GND), J1.23 (GND), J2.2, J4.4 (GND), J8.2, J9.11, SW21.2, SW23.C
MOSI: J1.5 (017), J4.1 (MOSI)
unnamed: D1.2 (A), SW1.1
unnamed: D2.2 (A), SW2.1
unnamed: D3.2 (A), SW3.1
unnamed: D4.2 (A), SW4.1
unnamed: D5.2 (A), SW5.1
unnamed: D6.2 (A), SW6.1
unnamed: D7.2 (A), SW7.1
unnamed: D8.2 (A), SW8.1
unnamed: D9.2 (A), SW9.1
unnamed: D10.2 (A), SW10.1
unnamed: D11.2 (A), SW11.1
unnamed: D12.2 (A), SW12.1
unnamed: D13.2 (A), SW13.1
unnamed: D14.2 (A), SW14.1
unnamed: D15.2 (A), SW15.1
unnamed: D16.2 (A), SW16.1
unnamed: D17.2 (A), SW17.1
unnamed: D18.2 (A), SW18.1
unnamed: D19.2 (A), SW19.1
unnamed: D20.2 (A), SW20.1
RST: J1.22 (RST), SW21.1
SCK: J1.6 (020), J4.2 (SCK)
col0: J1.13 (009), J9.5
col1: J1.14 (010), J9.4
col2: J1.15 (111), J9.3
col3: J1.16 (113), J9.2
col4: J1.17 (115), J9.1
col5: J1.11 (104), J8.12, S1.2 (CENTER), SW5.2, SW10.2, SW15.2, SW20.2, SW23.S1
col6: J1.10 (011), J8.11, S1.6 (D), SW4.2, SW9.2, SW14.2, SW19.2
col7: J1.9 (100), J8.10, S1.3 (C), SW3.2, SW8.2, SW13.2, SW18.2
col8: J1.8 (024), J8.9, S1.4 (B), SW2.2, SW7.2, SW12.2, SW17.2
col9: J1.7 (022), J8.8, S1.1 (A), SW1.2, SW6.2, SW11.2, SW16.2
encA: J1.32 (102), SW23.A
encB: J1.33 (107), SW23.B
row0: D1.1 (K), D2.1 (K), D3.1 (K), D4.1 (K), D5.1 (K), J1.2 (008), J8.7, J9.6
row1: D6.1 (K), D7.1 (K), D8.1 (K), D9.1 (K), D10.1 (K), J1.12 (106), J8.6, J9.7
row2: D11.1 (K), D12.1 (K), D13.1 (K), D14.1 (K), D15.1 (K), J1.18 (002), J8.5, J9.8
row3: D16.1 (K), D17.1 (K), D18.1 (K), D19.1 (K), D20.1 (K), J1.19 (029), J8.4, J9.9
row4: J1.20 (031), J8.3, J9.10, S1.5 (COMMON), SW23.S2

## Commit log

2023-11-02 add connector
    [connector.kicad_pcb, connector.kicad_sch]
2023-11-06 add pcb draft, case
    [bottom-left.stl, bottom-right.stl, outline.dxf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]
2023-11-08 final pcb
    [bottom-left.stl, bottom-right.stl, logo.kicad_pcb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]
2023-11-09 small updates to silkscreen and logo
    [bottom-left.stl, bottom-right.stl, case_duet v15_bottom-left.stl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]
2023-11-10 improve niceview pin mappings
    [pcb.kicad_pcb, pcb.kicad_sch]
2023-11-10 add order number to logo
    [logo.kicad_pcb]
2023-11-21 rotate alps 5way footprint to correct position
    [pcb.kicad_pcb]
2023-11-26 simplify connector and reduce size
    [connector.kicad_pcb, connector.kicad_sch]
2023-11-26 simplify pcb, reduce cover size
    [case_duet v15_bottom-left.stl, case_duet v15_bottom-right.stl, case_duet v15_top-left-display.stl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]
2023-11-29 small updates
    [connector-left.step, connector.kicad_pcb, pcb.kicad_pcb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]
2023-11-30 update connector to 1.2mm thickness
    [connector-left.step, connector-right.step, connector.kicad_pcb]
2023-12-01 revert shape changes to pcb
    [outline.dxf, pcb.kicad_pcb]
2023-12-01 revert shape to case, update center magnets and display position
    [case_duet-0.2 v14_bottom-left.stl, case_duet-0.2 v14_bottom-right.stl, case_duet-0.2 v14_top-left-display.stl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]
2023-12-02 remove thin walls from bottom
    [case_duet-0.2 v14_bottom-left.stl, case_duet-0.2 v14_bottom-right.stl, case_duet-0.2 v14_top-left-display.stl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]
2023-12-07 change angle to 20
    [outline.dxf, pcb.kicad_pcb]
2023-12-11 move mcu to right, add encoder
    [connector-left.step, connector-right.step, pcb.kicad_pcb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]
2024-01-01 pcb 0.3
    [pcb.kicad_pcb, pcb.kicad_sch]
2024-01-01 connector 0.3
    [connector.kicad_pcb]
2024-01-01 fix pcb silkscreen
    [pcb.kicad_pcb, pcb.kicad_sch]
2024-01-01 small case updates
    [case_duet-0.2 v33_bottom-left.stl, case_duet-0.2 v33_bottom-right.stl, case_duet-0.2 v33_top-left.stl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]
2024-01-14 small connector improvement
    [connector.kicad_pcb]
2024-01-16 final PCBs
    [connector.kicad_pcb, pcb.kicad_pcb]
2024-01-17 final case
    [case_duet v39_bottom-left.stl, case_duet v39_bottom-right.stl, case_duet v39_top-left-cover.stl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]
